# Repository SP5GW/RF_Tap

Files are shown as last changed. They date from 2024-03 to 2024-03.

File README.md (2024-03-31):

## RF Tap

<p align="center">

</p> 

## Credits

* Wes Hayward W7ZOI and Bob Larkin W7PUA for great base design of RF Tap described in QST June 2001 issue.
* Barry L. Dorr for detailed analysis of resistive pi attenuator design.
* Fesz (owner of Fesz Electronics youtube channel) for great hints regarding how to match ltspie simulations to NanoVNA measurements - You rock Fesz!!!

## Design Overview
RF Tap is a device used to extract or monitor radio frequency (RF) signals from a transmission line without significantly disturbing the original signal. The RF signal at Tap output is attenuated to a level that is safe for measurement equipment such as oscilloscope. In case of this particular design attenuation is fixed to -40dB (voltage at RFTap output is x100 lower then one, which is present at the transmission path). All three RF Tap terminals have 50ohm impedance.
This design is based on work by Wes Hayward W7ZOI and Bob Larkin W7PUA described in [1]. The only modification made here is the use of precission potentiometer instead of one of the resistors used to attenuate RF signal for precise attenuation level adjustment.

Circuit Schematics:

<p align="center">
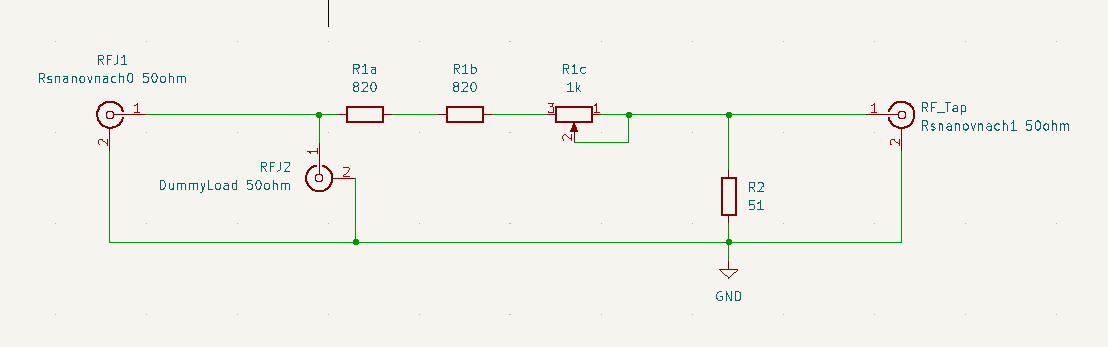
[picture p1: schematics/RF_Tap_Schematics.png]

</p>

Resistors R1a, R1b and R1c shall be 500mW rated. R2 can be 125mW rated. Please note that if you do not terminate RF path with 50ohm dummy load or antenna, power (Prms) dissipated on one of R1 resistors goes up to 1.3W!

Calculations of resistor values for given level of attenuation:

<p align="center">
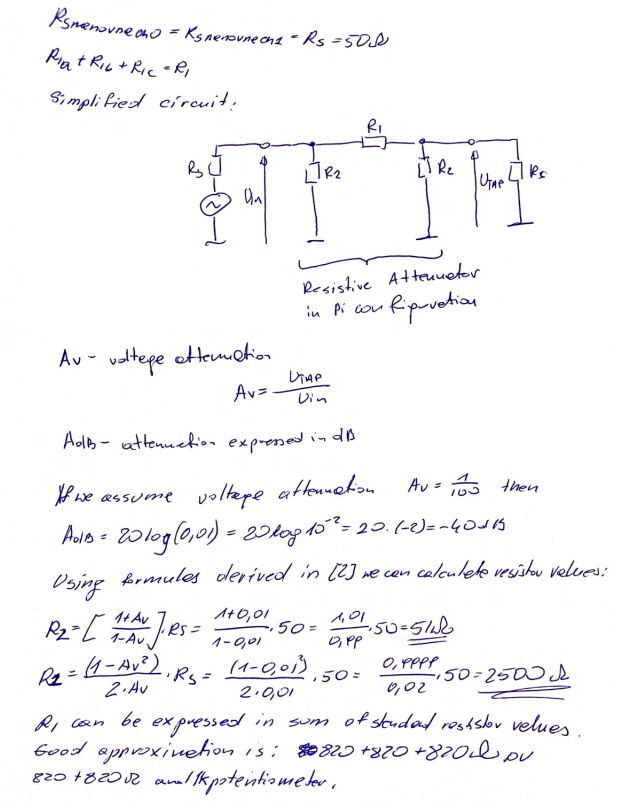
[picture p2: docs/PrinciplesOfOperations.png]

</p>

## Circuit Simulations

To be able to relate simulation results to NanoVNA measurements the first step is to establish measurement correction, which Nanovna calculates as part of calibration process.

<p align="center">
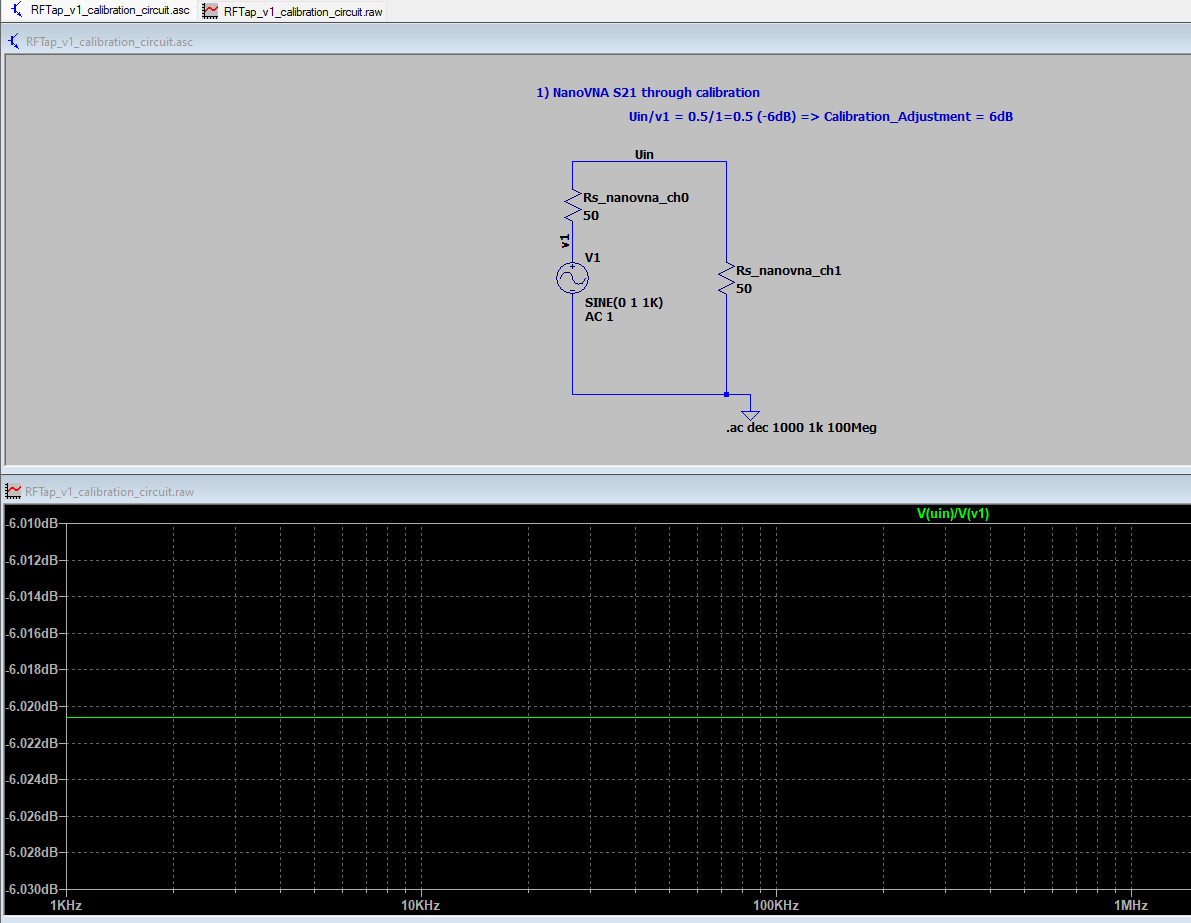
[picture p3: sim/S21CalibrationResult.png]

</p>

As can be seen from the results above, in our case the calibration correction is +6dB, which is added to all measurement results.

Now we can simulate RF Tap attenuation levels for unterminated and terminated with 50ohm resistor RF Paths:

<p align="center">
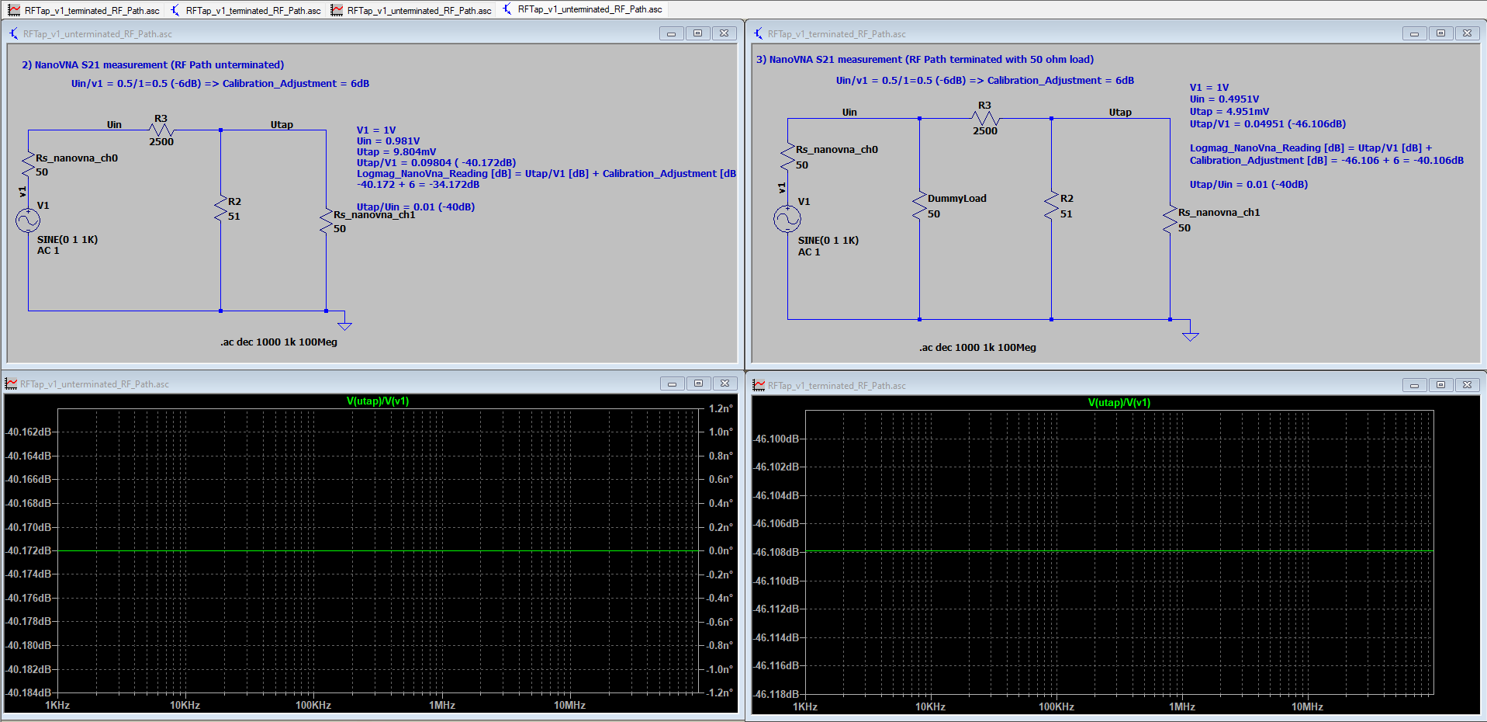
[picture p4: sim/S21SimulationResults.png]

</p>

In case of unterminated RF Path attenuation of RF Tap is equal -34dB and when the RF Path is terminated with 50ohm load attenuation increases to -40dB. 

As can be seen in Measurements section simulation results match perfectly actual measurements.

Simulation of the impact of parasitic capacitance present in the circuit and effect of corrective capacitance added in parallel to resistor R1 can be found below:

<p align="center">
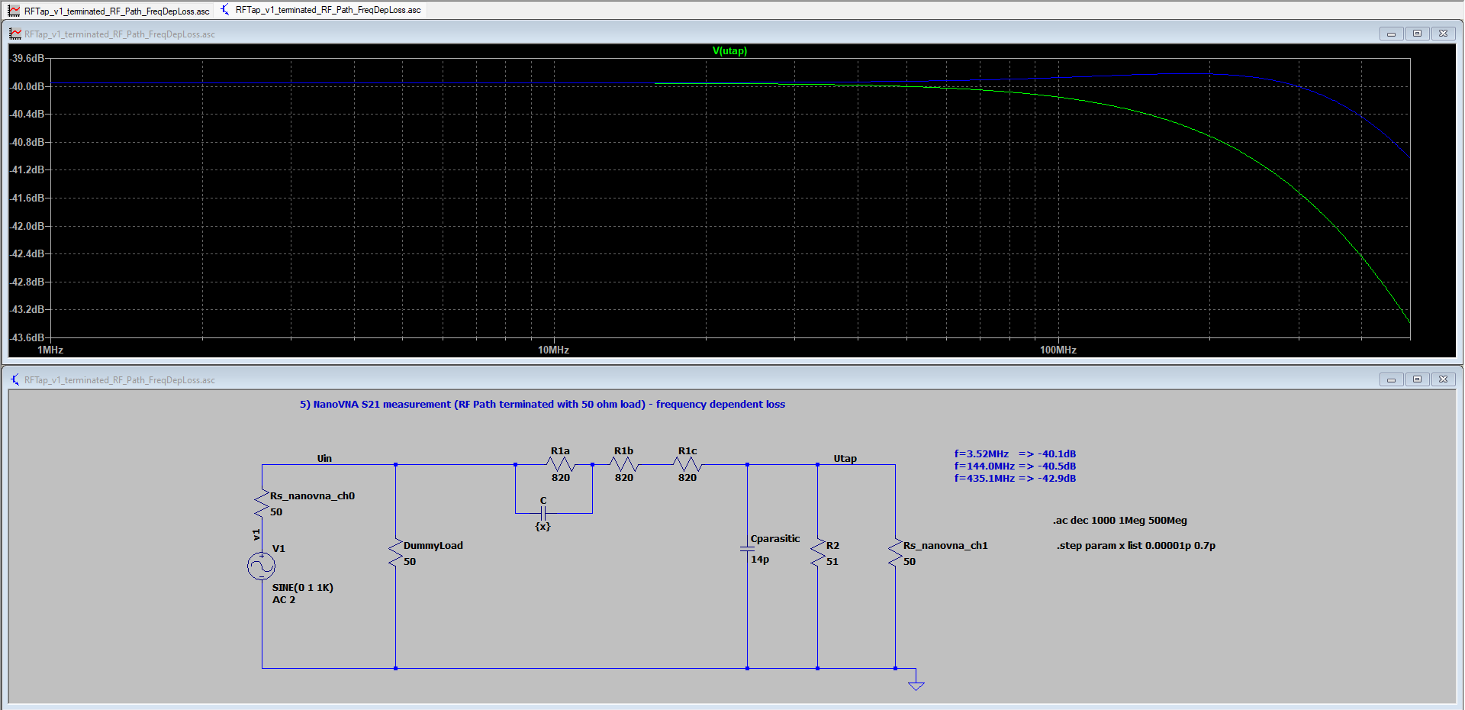
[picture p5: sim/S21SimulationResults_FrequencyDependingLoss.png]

</p>

Finally, calculations of resistor power ratings is given below (simulation run for peak power value of 100W):

<p align="center">
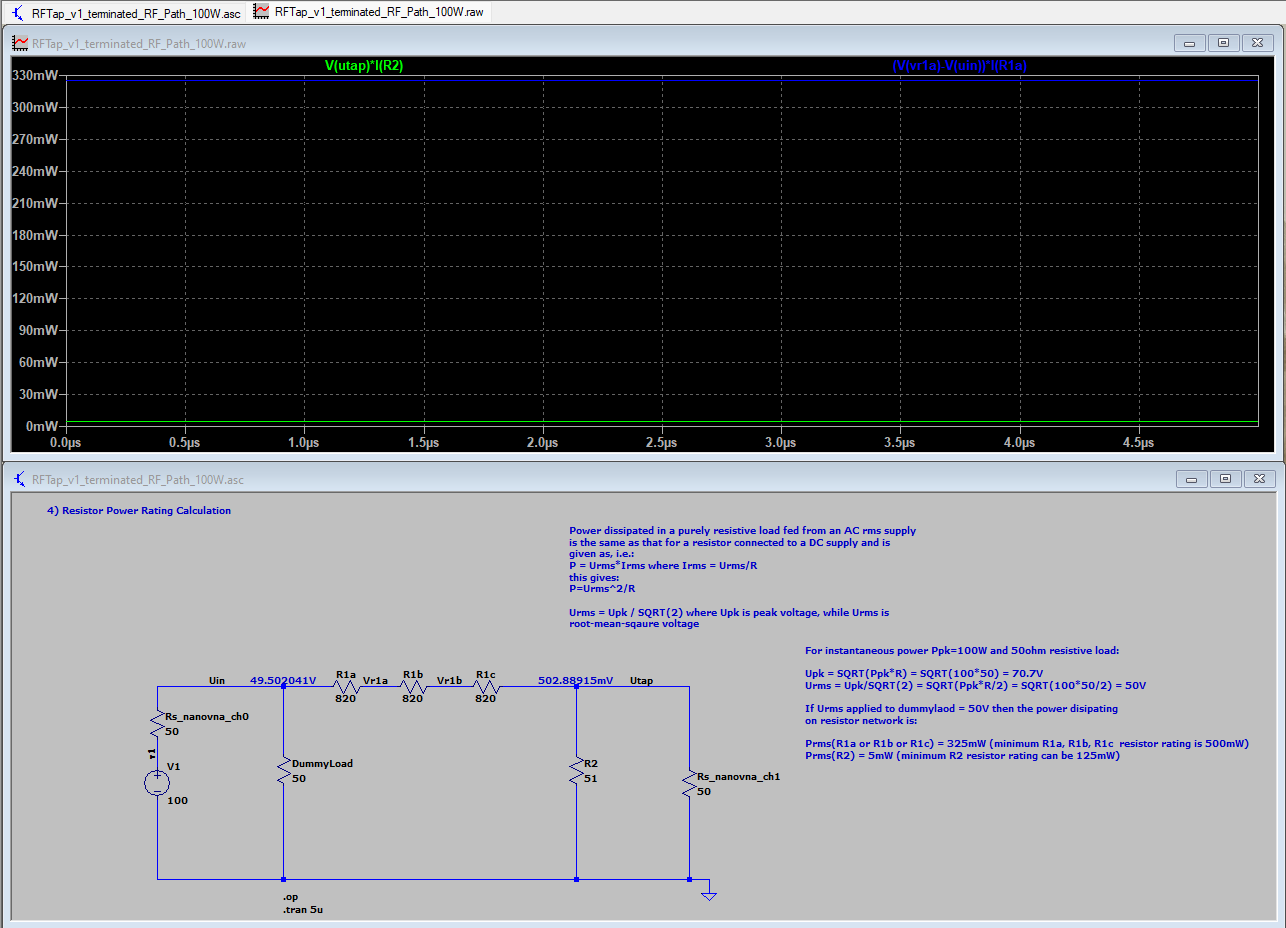
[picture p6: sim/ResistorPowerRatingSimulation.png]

</p>

## Measurements

### Device frequency response measured between one of RF path ends and RF tap output (another RF path end is terminated with 50ohm dummy load)

<p align="center">
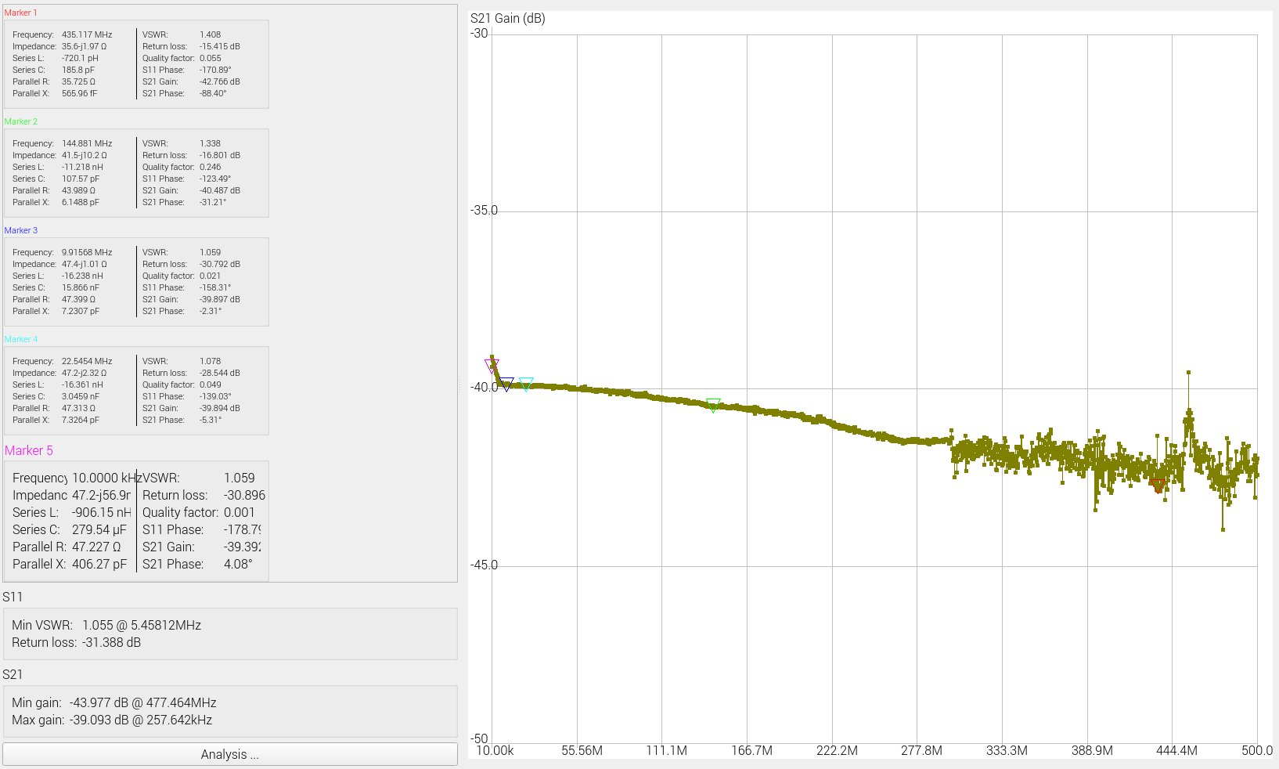
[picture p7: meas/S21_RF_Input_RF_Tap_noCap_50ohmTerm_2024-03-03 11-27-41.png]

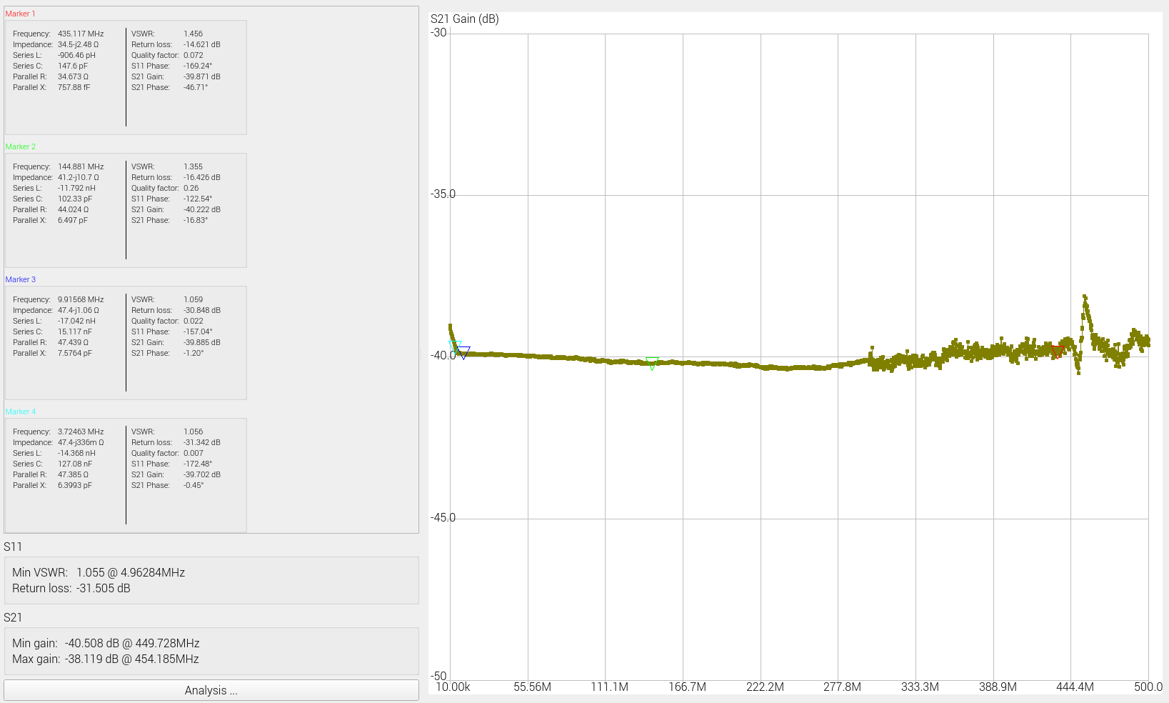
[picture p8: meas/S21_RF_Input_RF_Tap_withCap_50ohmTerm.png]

</p>

Picture to the right shows RF Tap's S21 curve when capaitor C is present. 
Picture to the left shows Tap's S21 curve when capacitor C is not present. 
The cap C reduces attenuation for signals above 144MHz.

### VSWR measured at one of RF path ends (another RF path end is terminated with 50ohm dummy load)

<p align="center">
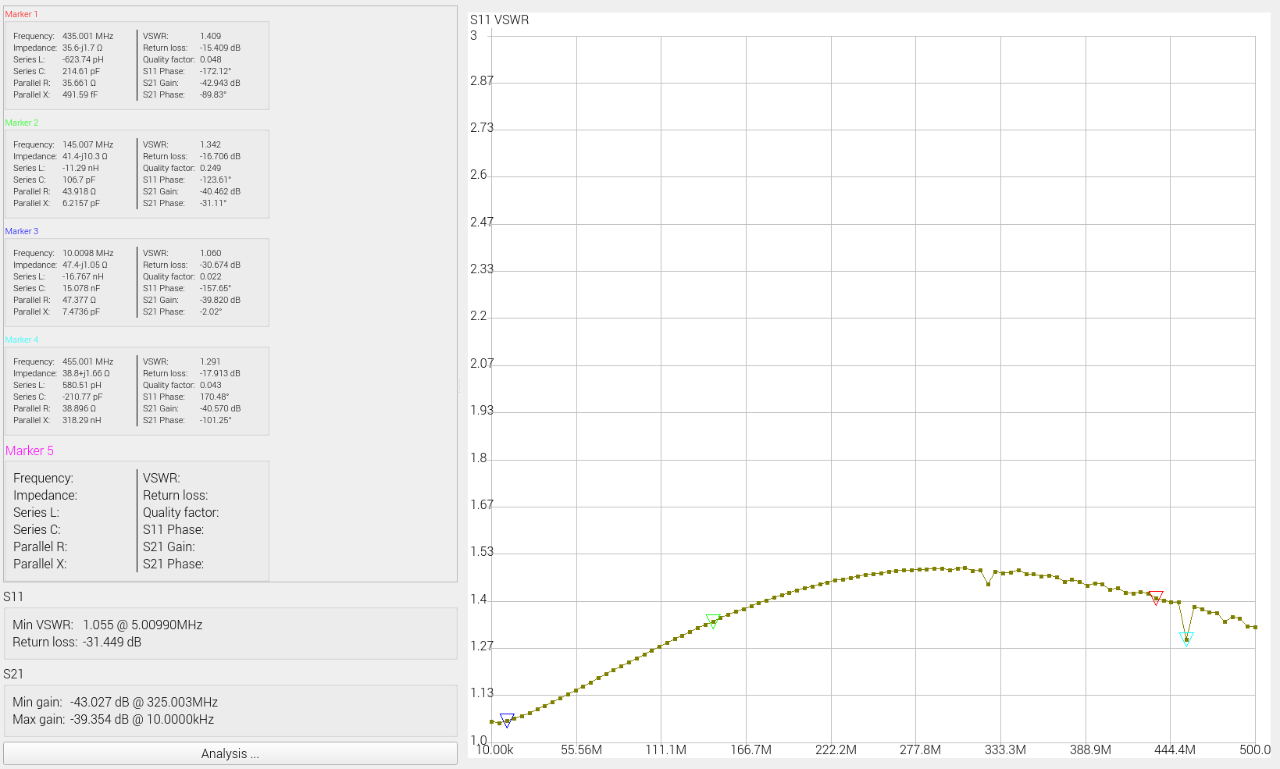
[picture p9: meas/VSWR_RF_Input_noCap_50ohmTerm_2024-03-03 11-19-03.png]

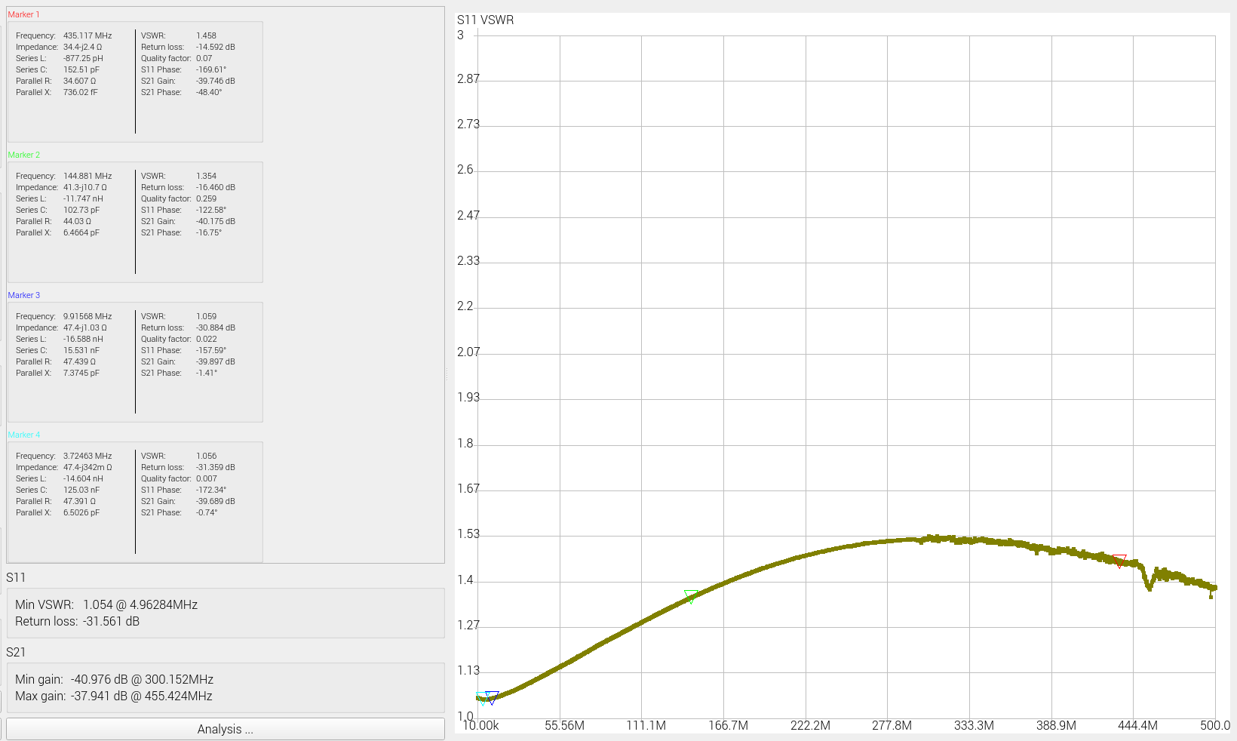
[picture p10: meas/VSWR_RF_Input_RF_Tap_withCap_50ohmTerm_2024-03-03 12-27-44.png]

</p>

Picture to the right shows RF Tap's VSWR curve measured at RF input for device with capaitor C.
Picture to the left shows Tap's VSWR curve measured at RF input for device with no capacitor C.
In both cases other end of RF path is terminated with 50 ohm dummy load.
It can be observed that while capacitor C improves Tap's frequency response seen from Tap output (attenuation is closer to -40dB accross enntire band) it also slightly increases VSWR measured at one of RF path ends.

### Insertion loss measured at RF path ends (RF Tap termination does not impact measurements)

<p align="center">
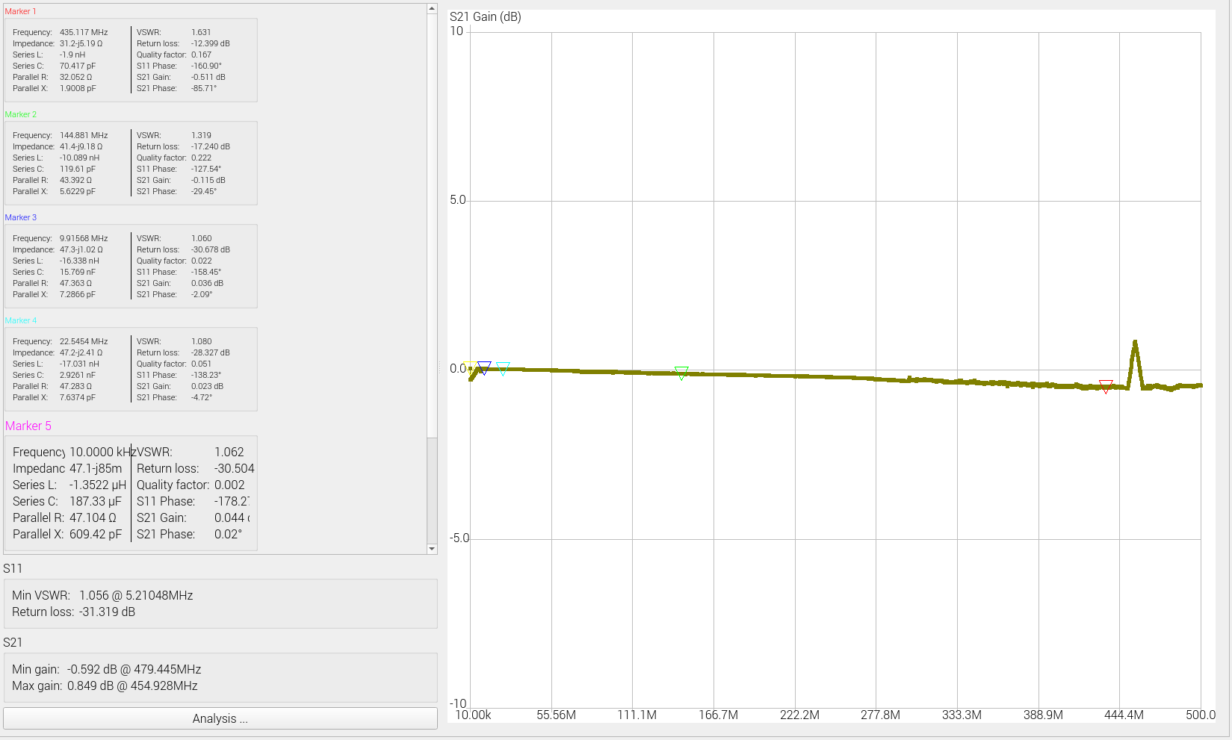
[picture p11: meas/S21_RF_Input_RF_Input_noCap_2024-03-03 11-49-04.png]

</p>

Insertion loss caused by RF Tap is not greater then -0.5dB accross entire band (DC-500MHz). Presence of Cap does not impact insertion loss level in any significant way.
RF Tap termination does not impact measurement results i.e. insertion loss is the same for RF Tap output terminated with 50ohm resistor and when RF Tap is left open.

## RF Tap adaptation to high impedance measurement device such as scope

When Tap is connected to high impedance measurement device such as scope with input impedance equal or higher then 1Mohm, its resistor R3 shown on the diagram below has to be doubled in value (increase from 2.5kohm to 5kohm) in order to maintain desired level of attenuation (-40dB / 1:100 Voltage attenuation). 
Simulation results: 

<p align="center">
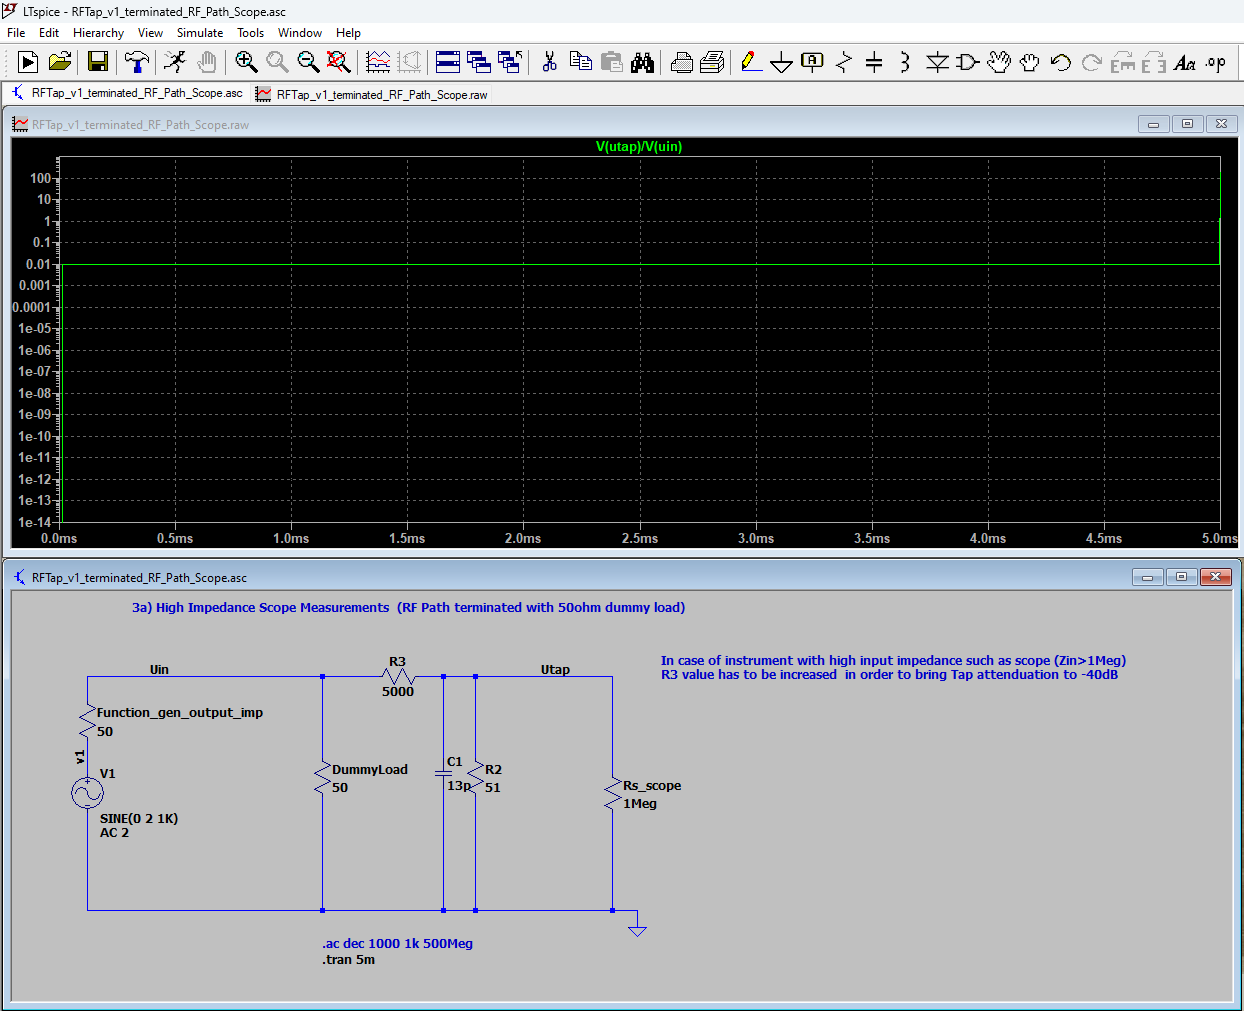
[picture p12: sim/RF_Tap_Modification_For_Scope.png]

</p>

Actual voltage measurements, input voltage supplied from functional generator (50ohm output impedance):

<p align="center">
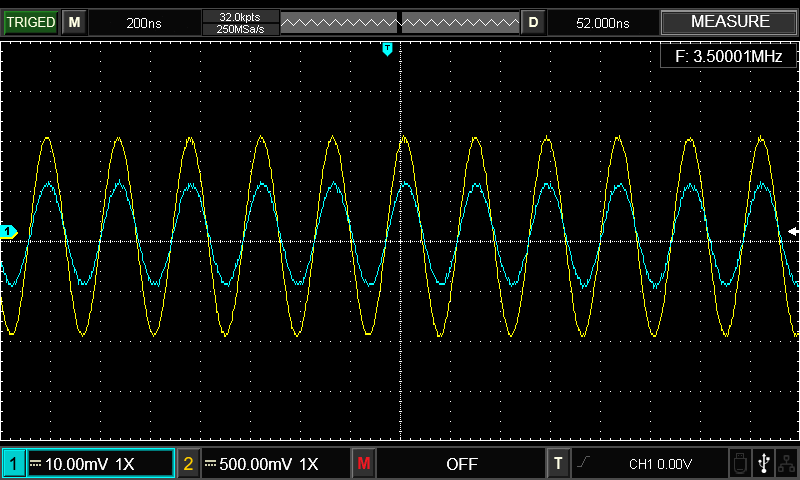
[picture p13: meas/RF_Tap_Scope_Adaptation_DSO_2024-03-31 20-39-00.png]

</p>

In practice resistor R3 is series of 2x820ohm resistors and 5k precission potentiometer. 
## References

[1] "Simple RF-Power Measurement", QST June 2001 by Wes Hayward W7ZOI and Bob Larkin W7PUA

[2] "Ten Essential Skills for Electrical Engineers" by Barry L. Dorr, Willey 2014, Chapter: "How to Design Resistive Circuits"

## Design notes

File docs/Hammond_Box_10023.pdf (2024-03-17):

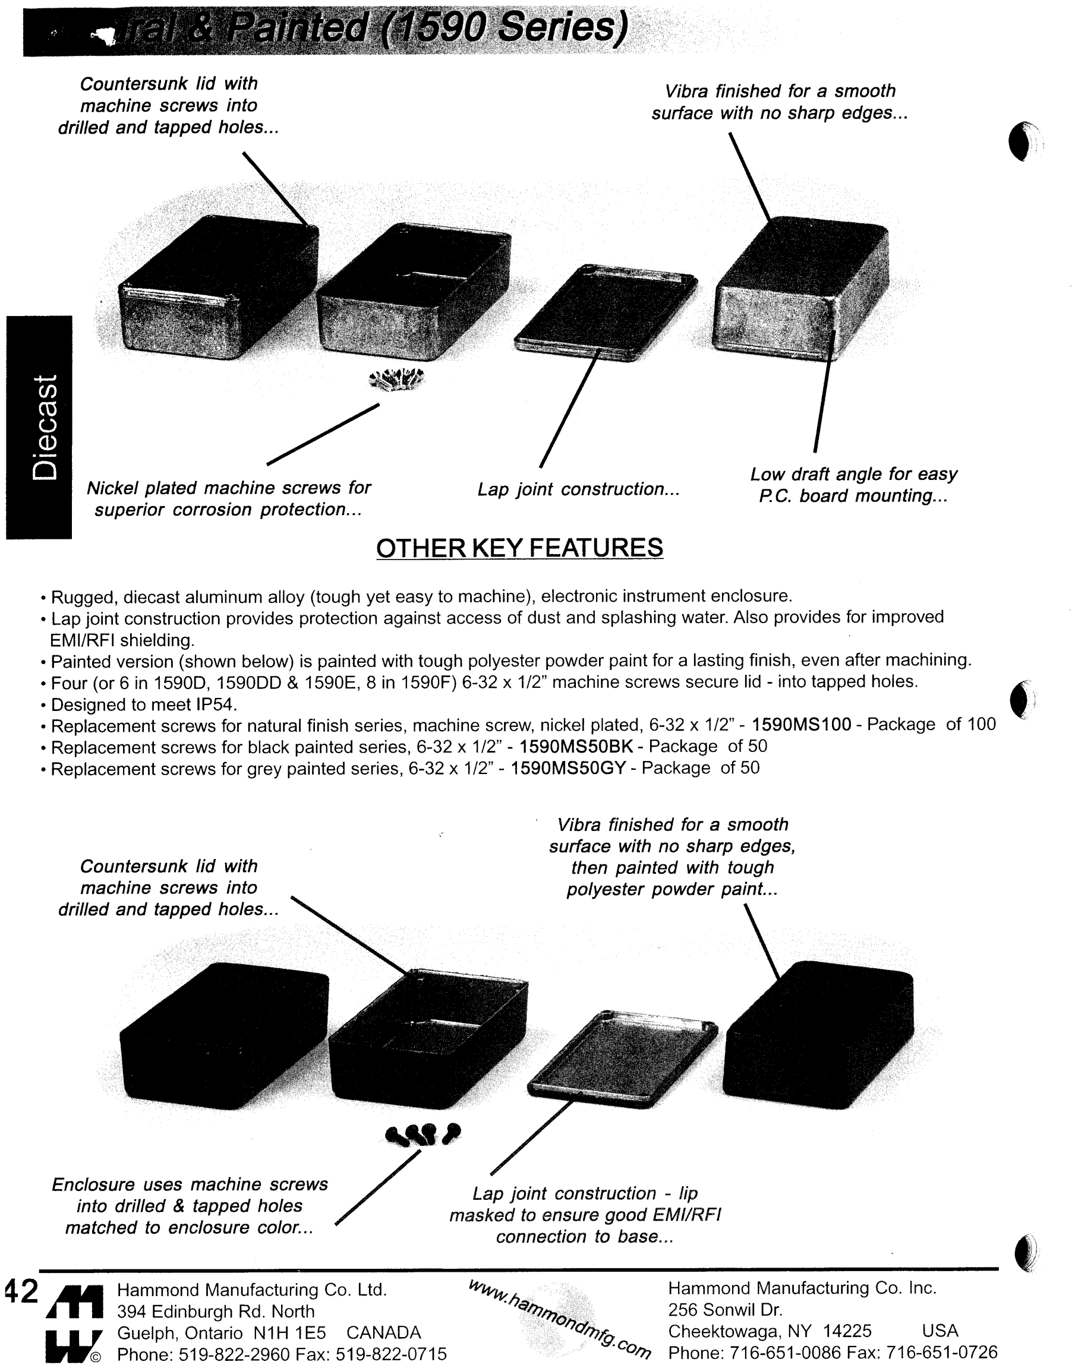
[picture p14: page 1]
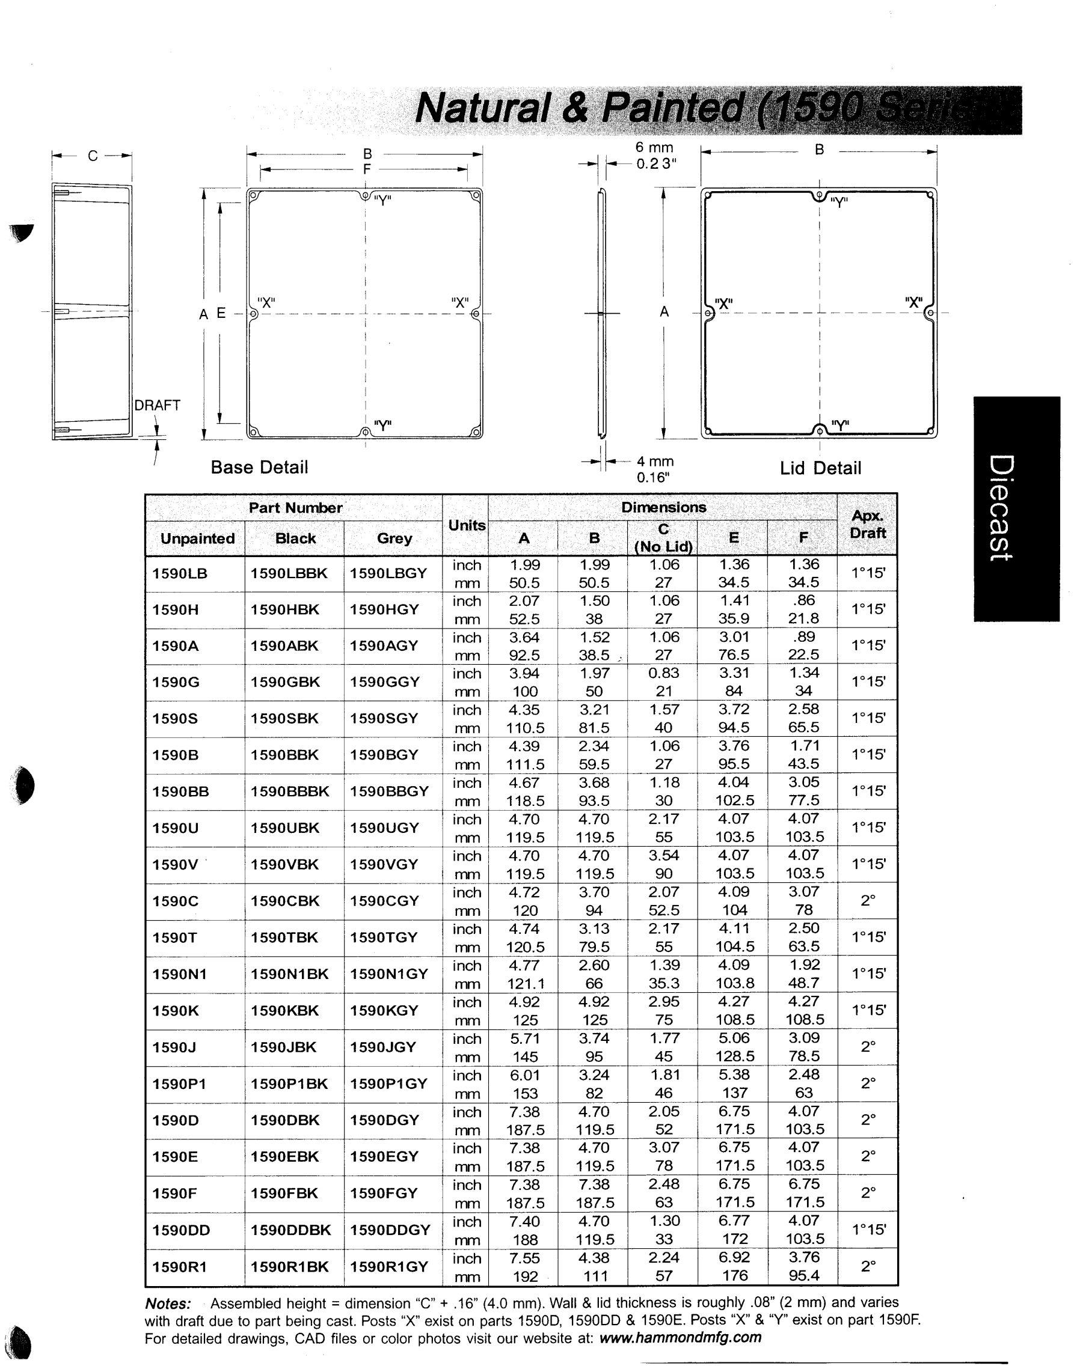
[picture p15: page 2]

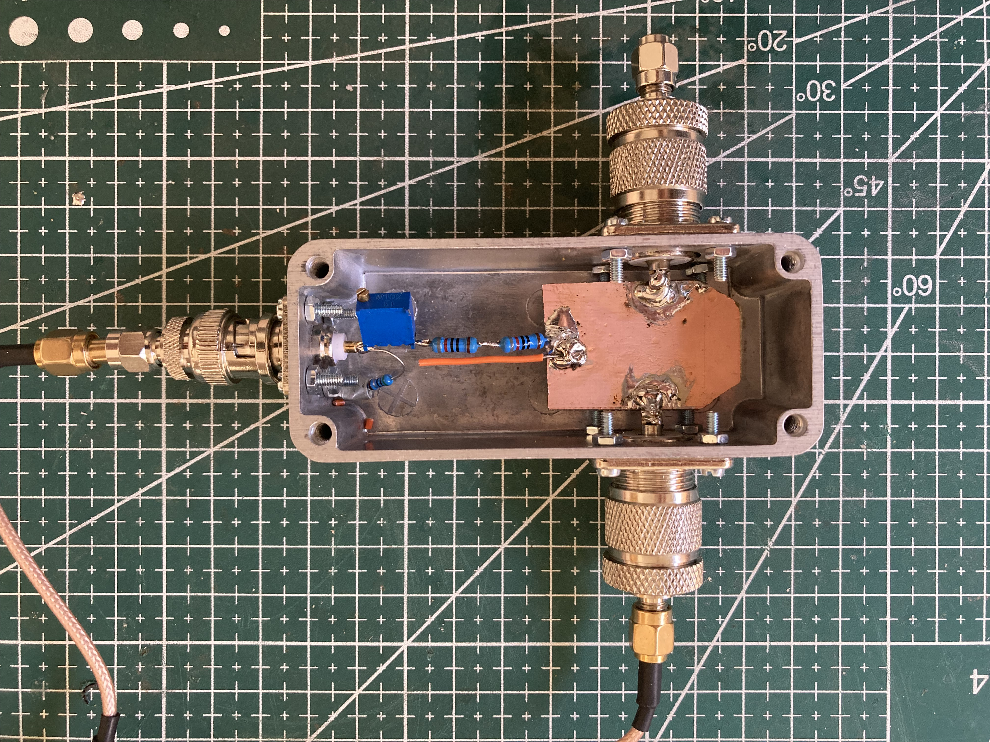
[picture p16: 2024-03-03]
img/InternalsWithCap.jpg

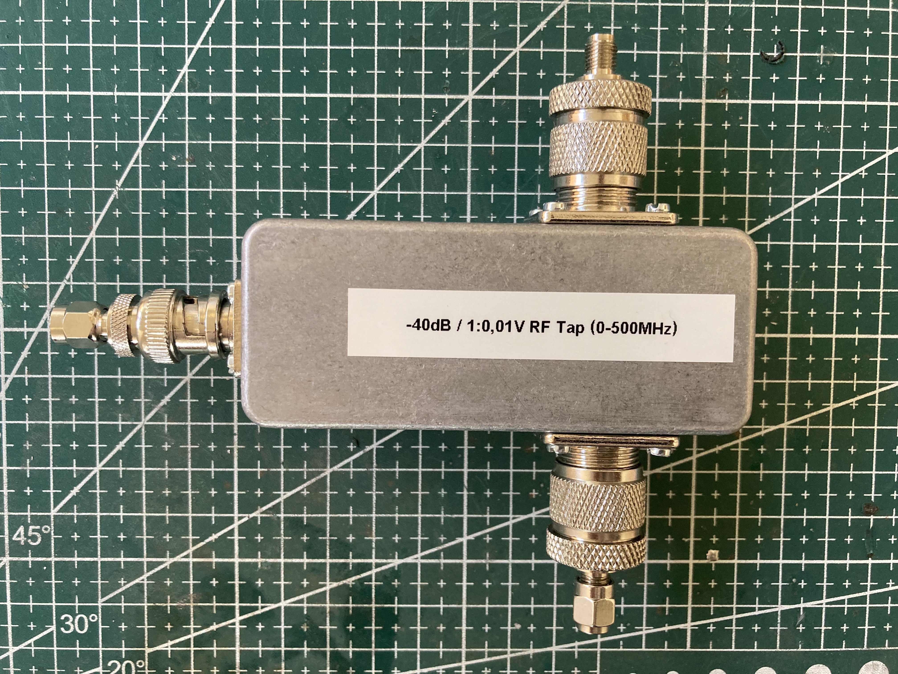
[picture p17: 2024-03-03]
img/FinalProduct.jpg

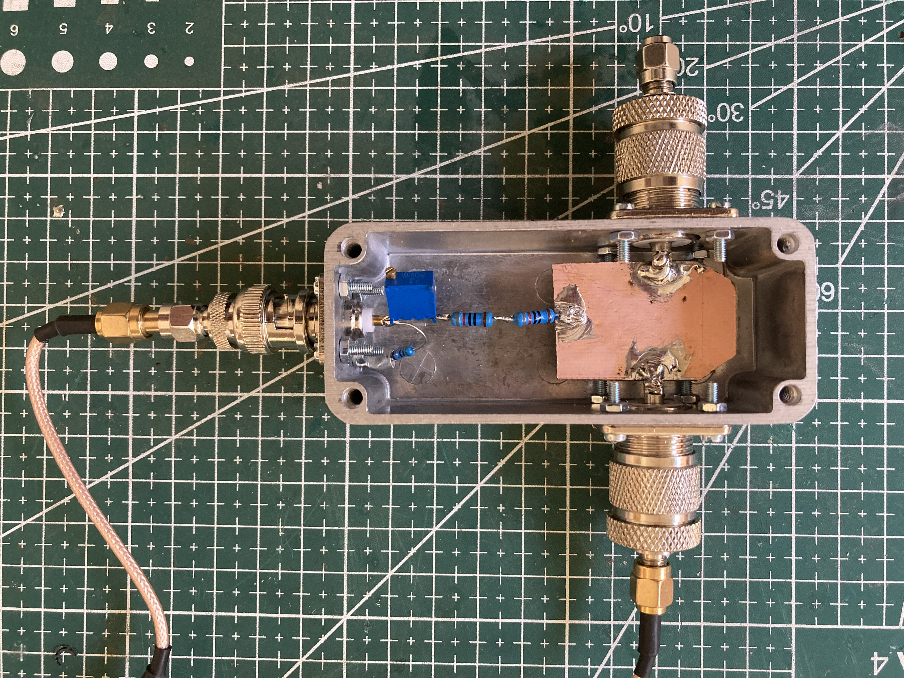
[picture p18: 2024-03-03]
img/InternalsWithoutCap.jpg

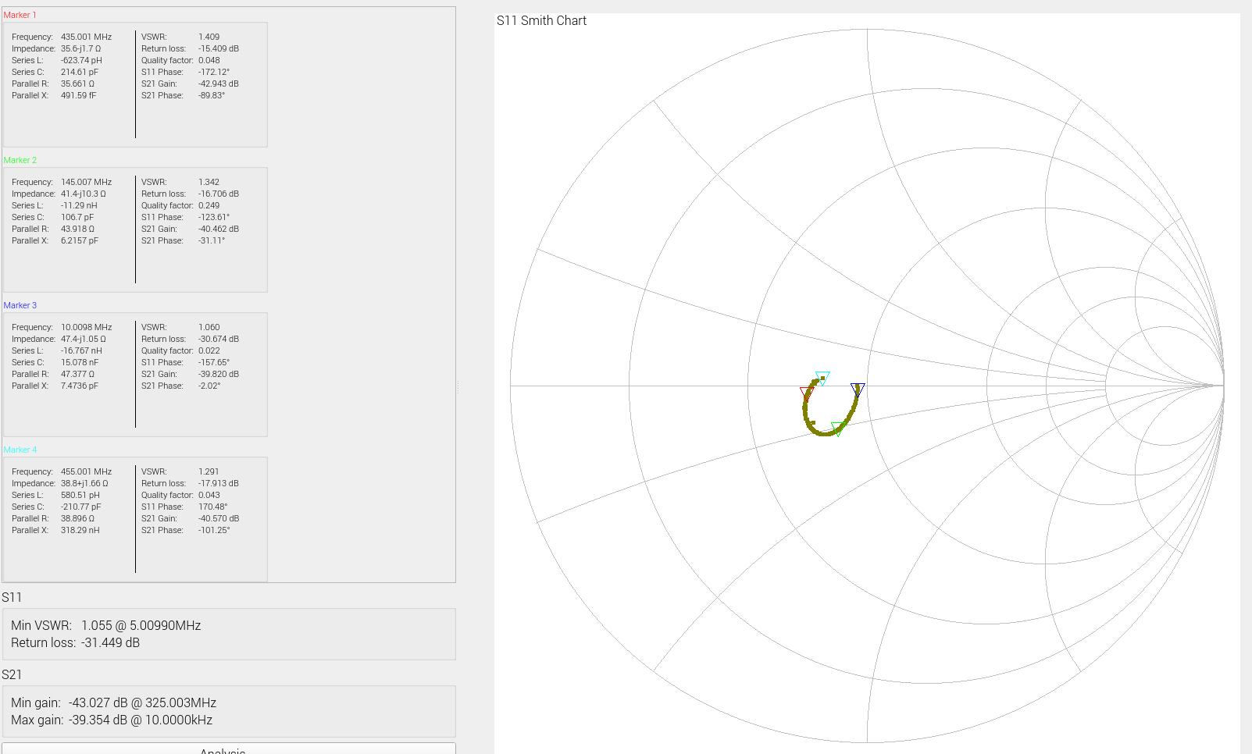
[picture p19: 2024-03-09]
meas/Smith_RF_Input_noCap_50ohmTerm_024-03-03 11-16-14.png

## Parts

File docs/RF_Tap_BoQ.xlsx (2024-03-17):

# | Product Code | Qty | Description | Seller | Unit Price [PLN] | Sub Total [PLN]
1 | 1590A | 1 | Hammond Box 92.5x38.5x31mm | Farnell | 35.45 | 35.45
2 | MF50 820R | 2 | resistor MF50 820R RES, 820R, 1%, 500MW, AXIAL, METAL FILM | Farnell | 4.7 | 9.4
3 | MF25 51R | 1 | resistor MF25 51R RES, 51R, 1%, 250MW, AXIAL, METAL FILM | Farnell | 3.3 | 3.3
4 | PR1K 3296Y | 1 | potentiometer (10 turns) 1kom Helitrim 3296Y, 0,5W | AVT | 1.6 | 1.6
5 | GNIAZDO UC1 | 2 | pannel screw mounted UC1 socket | AVT | 4.9 | 9.8
6 | GNIAZD BNC4 | 1 | pannel screw mounted BNC socket | AVT | 6.9 | 6.9
7 | B3X6/BN384 | 1 | M3 screws (6mm) - 2 packages of 10 pcs each | AVT | 3 | 3
8 | B3/BN115 | 1 | M3 nut - 2 packages of 10 pcs each | AVT | 3 | 3
 |  |  |  |  |  | 72.45

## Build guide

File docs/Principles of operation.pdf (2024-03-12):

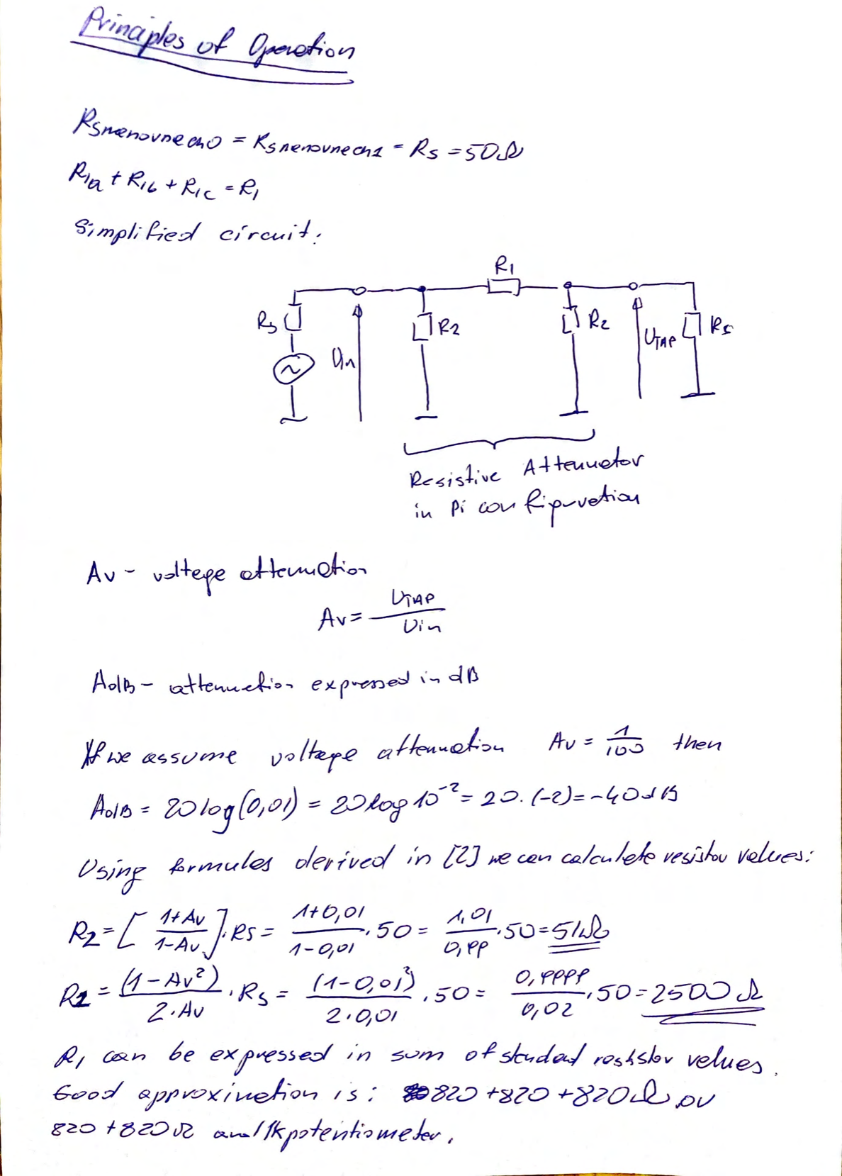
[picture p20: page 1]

L---o,--
~ cJ
I (9 Q~
l

AV - v-:;,l +~ col-kl-M-4 ~o~ Av;;;

Av~ ,:~ -lhe~

A1 ,,_, "" zo le:) {tl1 & ;) "" z,::> /ot ,lo-.,=- 2. o (-e)= - 4 o ..1 lj

t) c,/i,!f' /1,,.,,.,, u le.t o/e; i I/ cd I YJ [Z J Mt c,;v, c.,/c~ /e4, wf,f.Jfov t1dueJ:

R ;:::. r 1-IA11)er - /ff°'0/1 5"o::; /4 0/ , {\
-..Z. l- '1-Av , - //- 0;01 1:0 f?f ,S-CJ ;5/J.Ju
r? .. _ {1 - Av?) 0 ( 4- 0, o J) 0/ 'f'P-Pf'
K.L- - 11 ,, ..... s = ,, , 5"0:: --,~o: 2~00 Jl

## z,,,..,v 2 1 0;01 (:J;OZ

/2; utS<,,,, 6 e ex /"'t'::.5 d /n ::,v,n o ,e sb,,I ,:,,./ ,-06 ,< ~lo v ve4, €½ 6-&-o.::/ 0./.7/'VO>c/~o,-., / .S ,' ~8?c.:J -1-2Z,0 +-cf ;?0~ .,0(/ ,
g20 f 8c::>Jc, (:il | 1/k;:?1-e;;I-/Que.fev'

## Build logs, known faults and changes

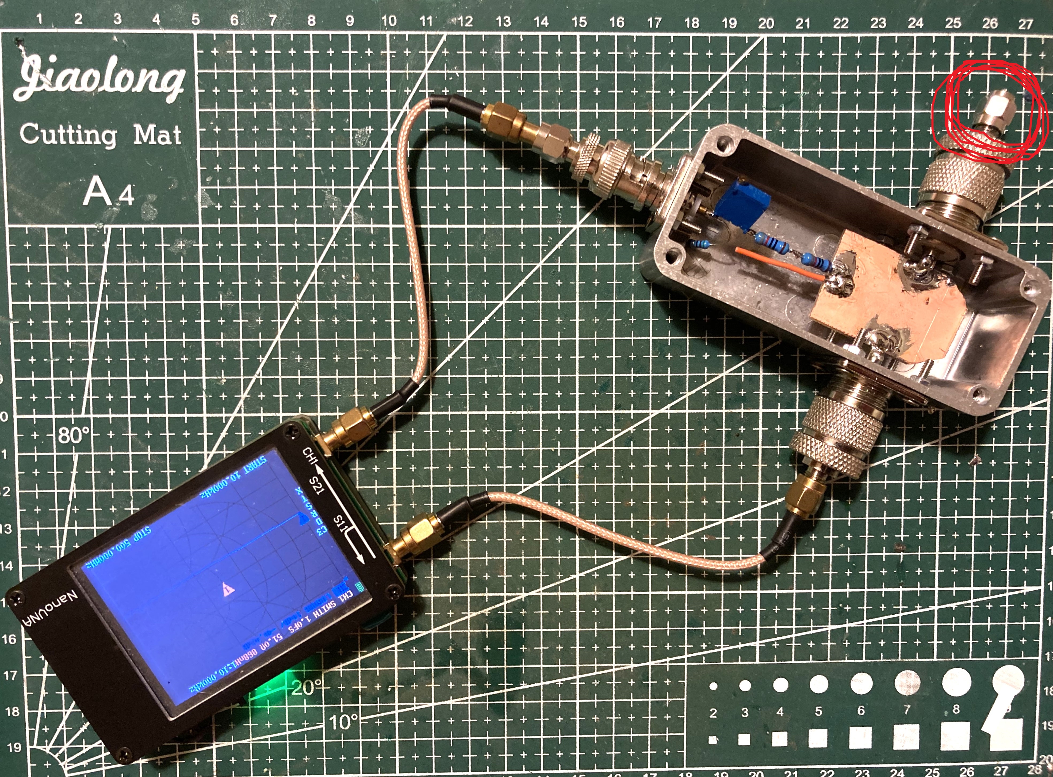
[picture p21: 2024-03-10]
img/MeasurementSetup_problem.jpg

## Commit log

2024-03-09 xls cleaned + qst article added
    [RF_Tap.xlsx]
2024-03-12 design overview improved
    [RF_Tap.xlsx, RF_Tap_Schematics.kicad_sch]
2024-03-12 resistor power rating remark added
2024-03-17 BoQ added + hammond box spec added
    [RF_Tap_BoQ.xlsx]
